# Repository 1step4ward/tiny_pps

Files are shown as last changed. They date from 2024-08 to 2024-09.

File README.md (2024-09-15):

# Tiny Programmable Power Supply

今は、USB機器向けのACアダプタやモバイルバッテリーは、一人一つ以上持っていると思います。最近では、そういった機器は、USB PD-PPSに対応していることが多く、USB PD-PPSとは、Power Delivery - Programmable Power Supplyと言う通り、電圧電流がプログラム可能な電源機能を持っていることを表しています。  

このリポジトリは、そのUSB PD PPSの機能を使った小型の可変電圧電源を作ることを目的としています。  

そして、同じような目的に使える素晴らしい製品がすでにありますので、興味のある人は、以下のリンクを参照ください。  
https://hackaday.io/project/192576-picopd-usb-c-pd-30-pps-trigger-with-rp2040

上記のものが日本では入手し難かったのと、単純に作りたかったため始めたプロジェクトです。

## Prototype 1.0

### ・外観
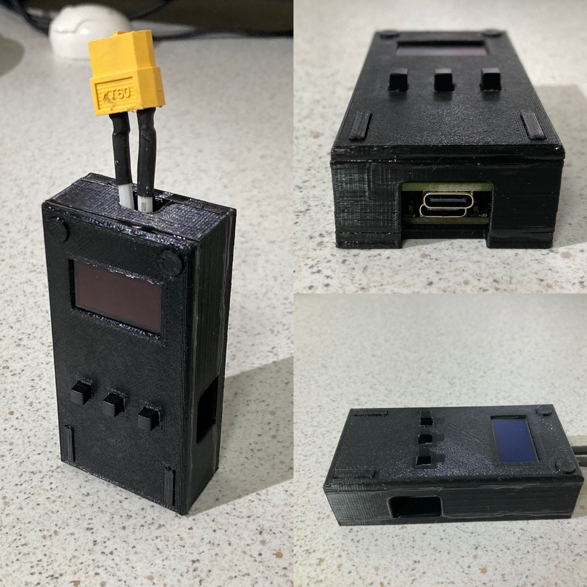
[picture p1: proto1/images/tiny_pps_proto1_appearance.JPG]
外観


### ・主要部品
- [AP33772使用 USB PD PPSコントローラー基板](https://aselectroworks.booth.pm/items/5621735)  
- Raspberry Pi Pico（代替品を使用）  
- [0.96インチ 128×64ドット有機ELディスプレイ(OLED) 白色](https://akizukidenshi.com/catalog/g/g112031/)  
- [タクトスイッチ](https://akizukidenshi.com/catalog/g/g112224)、[キートップ](https://akizukidenshi.com/catalog/g/g112429/)  
- パワーMOSFET IRFZ44N  
- コンデンサ  

出力のON/OFF回路部にパワーMOSFET、コンデンサを使用していますが、知識が乏しく適切な使用じゃないかもしれません。

### ・仕様
| 項目 | 数値 |
|-----|-----|
| 電圧範囲 | 3.3 - 21.0V 20mV刻み |
| 電流範囲 | 最大5A 50mA刻み |
|  | ※USB PD 3.0仕様の範囲、実際の使用時は電源ソースの能力による |
| 大きさ | 80 x 40 x 21mm |
| 重さ | 52g |
| 入出力 | 3ボタン、128x64 OLED、USB-C(電源ソース、プログラム)、XT60コネクタ(電力出力) |

### ・リンク
[ファームウェア](proto1/software/firmware/)  
[配線図](proto1/hardware/circuit/tiny_pps_proto1_bb.png)  
[ケースの3Dプリントモデル](proto1/hardware/3d-printed-case/)

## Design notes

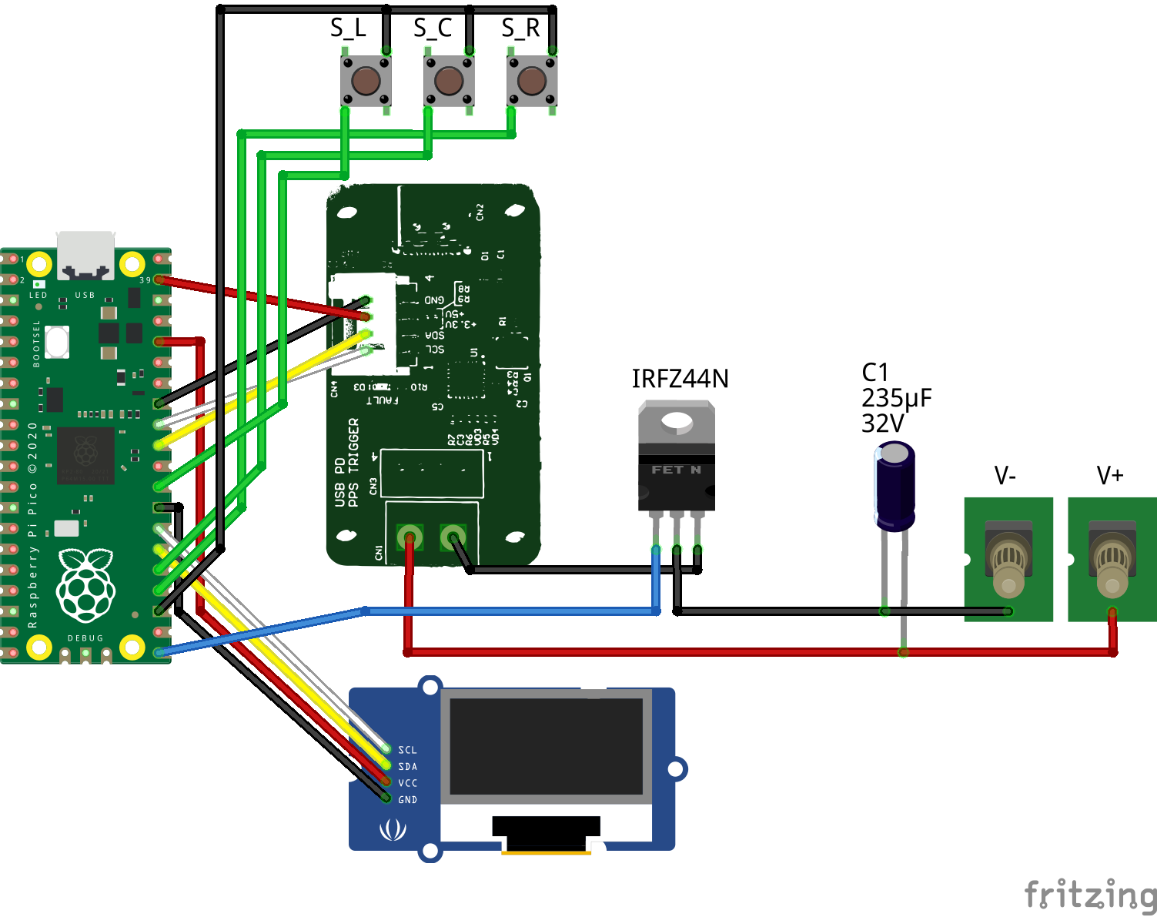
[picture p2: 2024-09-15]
proto1/hardware/circuit/tiny_pps_proto1_bb.png

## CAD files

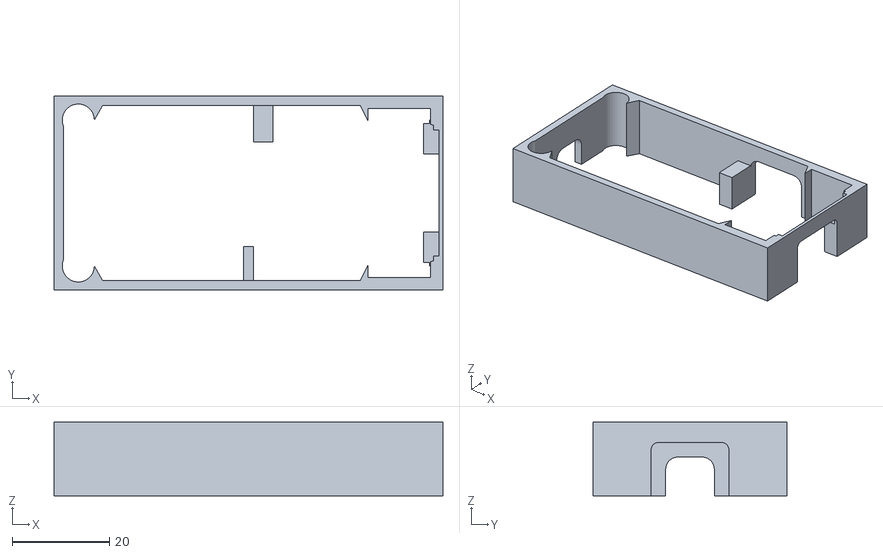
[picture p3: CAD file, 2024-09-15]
proto1/hardware/3d-printed-case/tinypps_proto1_wall.stl
80.0 x 40.0 x 15.2

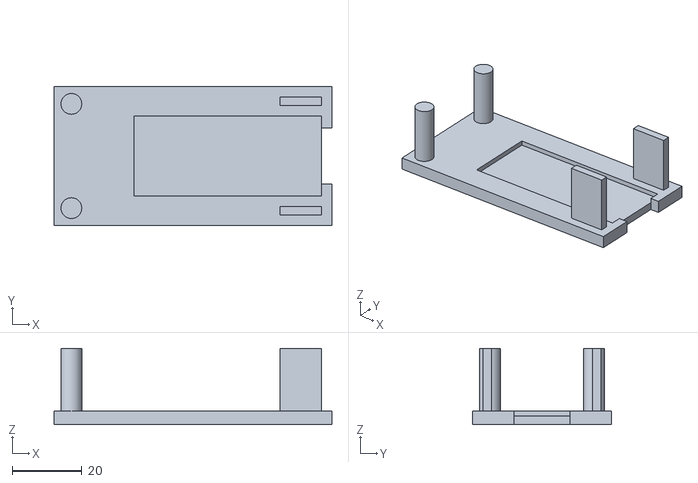
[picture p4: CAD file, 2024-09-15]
proto1/hardware/3d-printed-case/tinypps_proto1_bottom.stl
80.0 x 40.0 x 22.0

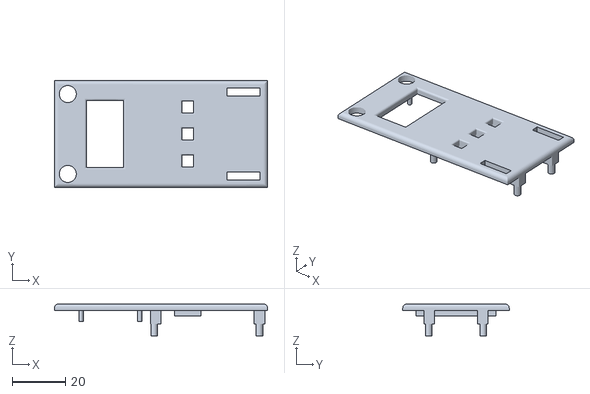
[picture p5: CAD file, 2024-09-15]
proto1/hardware/3d-printed-case/tinypps_proto1_top.stl
80.0 x 40.0 x 12.0

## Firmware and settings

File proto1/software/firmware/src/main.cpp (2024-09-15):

/*
  Example code that will cycle through all possble PPS voltage starting at 4.2V
  Will print out current reading through the 10mOhm sense resistor and blink LED
*/

#include <Arduino.h>
#include <AP33772_PS.h>
#include <Adafruit_GFX.h>
#include <Adafruit_SSD1306.h>

#define SCREEN_WIDTH 128 // OLED display width, in pixels
#define SCREEN_HEIGHT 64 // OLED display height, in pixels

// Declaration for an SSD1306 display connected to I2C (SDA, SCL pins)
// The pins for I2C are defined by the Wire-library. 
// On an arduino UNO:       A4(SDA), A5(SCL)
// On an arduino MEGA 2560: 20(SDA), 21(SCL)
// On an arduino LEONARDO:   2(SDA),  3(SCL), ...
#define OLED_RESET     -1 // Reset pin # (or -1 if sharing Arduino reset pin)
#define SCREEN_ADDRESS 0x3C ///< See datasheet for Address; 0x3D for 128x64, 0x3C for 128x32
Adafruit_SSD1306 display(SCREEN_WIDTH, SCREEN_HEIGHT, &Wire, OLED_RESET);
AP33772_PS usbpd(Wire1); // Automatically wire to Wire0,


bool state = 0;
int voltage = 3300;
int current = 3000;
int maxVoltage = 10000;
int minVoltage = 3300;
int maxCurrent = 3000;

int button_count0 = 0;
int button_count1 = 0;
int button_count2 = 0;
int button_count3 = 0;

int mode = 0;

/**
 * @brief Debug code to quickly check power supply profile PDOs
 * dump all PDOs profile into Serial port
 */
void printPDO_PPS()
{
    byte numPDO = usbpd.getLowCtrl()->getNumPDO();
    PDO_DATA_T* pdoData = usbpd.getLowCtrl()->getPdoData();
    for (byte i = 0; i < numPDO; i++)
    {
        if ((pdoData[i].byte3 & 0xF0) == 0xC0) // PPS PDO
        {
            display.print(i + 1); // PDO position start from 1
            display.print(":");
            display.print((float)(pdoData[i].pps.minVoltage) * 100 / 1000);
            display.print("V~");
            display.print((float)(pdoData[i].pps.maxVoltage) * 100 / 1000);
            display.print("V@");
            display.print((float)(pdoData[i].pps.maxCurrent) * 50 / 1000);
            display.println("A");
            
            minVoltage = pdoData[i].pps.minVoltage * 100;
            maxVoltage = pdoData[i].pps.maxVoltage * 100;
            maxCurrent = pdoData[i].pps.maxCurrent * 50;
        }
    }
}

void setup()
{
  Wire.setSDA(20);
  Wire.setSCL(21);
  Wire.begin();

  usbpd.setup(26, 27);

  pinMode(25, OUTPUT); //Built in LED
  pinMode(23, OUTPUT); //Load Switch
  pinMode(16, INPUT_PULLDOWN); //MOSFET

  pinMode(18, INPUT_PULLUP);
  pinMode(19, INPUT_PULLUP);
  pinMode(22, INPUT_PULLUP);

  Serial.begin(115200);

  // SSD1306_SWITCHCAPVCC = generate display voltage from 3.3V internally
  if(!display.begin(SSD1306_SWITCHCAPVCC, SCREEN_ADDRESS)) {
    Serial.println(F("SSD1306 allocation failed"));
    for(;;); // Don't proceed, loop forever
  }
  // Clear the buffer
  display.clearDisplay();
  display.setTextSize(1);             // Normal 1:1 pixel scale
  display.setTextColor(SSD1306_WHITE);        // Draw white text
  display.setCursor(0,0);             // Start at top-left corner
  display.println("initializing...");
  display.display();

  usbpd.begin(); // Start pulling the PDOs from power supply

  digitalWrite(23, HIGH);

  // Clear the buffer
  display.clearDisplay();
  display.display();
}

void loop()
{
  char button[5] = "    ";

  display.clearDisplay();

  display.setTextSize(1);             // Normal 1:1 pixel scale
  display.setTextColor(SSD1306_WHITE);        // Draw white text
  display.setCursor(0,0);             // Start at top-left corner

  PinStatus lbutton, rbutton, mbutton;
  lbutton = digitalRead(22);
  rbutton = digitalRead(18);
  mbutton = digitalRead(19);

  if (mode == 0) {
    // voltage edit mode

    if (rbutton == LOW) {
      button[2] = 'x';
      button_count0 += 1;
      if (button_count0 > 5 && voltage < maxVoltage) {
        voltage += 100;
      }
    } else {
      button[2] = 'o';
      button_count0 = 0;
    }
    if (lbutton == LOW) {
      button[0] = 'x';
      button_count1 += 1;
      if (button_count1 > 5 && voltage > minVoltage) {
        voltage -= 100;
      }
    } else {
      button[0] = 'o';
      button_count1 = 0;
    }
  } else {
    // current edit mode

    if (rbutton == LOW) {
      button[2] = 'x';
      button_count0 += 1;
      if (button_count0 > 5 && current < maxCurrent) {
        current += 20;
      }
    } else {
      button[2] = 'o';
      button_count0 = 0;
    }
    if (lbutton == LOW) {
      button[0] = 'x';
      button_count1 += 1;
      if (button_count1 > 5 && current > 0) {
        current -= 20;
      }
    } else {
      button[0] = 'o';
      button_count1 = 0;
    }
  }

  if ((lbutton == LOW) && (rbutton == LOW)) {
    button_count3 += 1;
    if (button_count3 > 5) {
      if (mode == 0) {
        mode = 1;
      } else {
        mode = 0;
      }
      button_count3 = 0;
    }
  } else {
    button_count3 = 0;
  }

  bool enable = false;
  if (mbutton == LOW) {
    button[1] = 'x';
    button_count2 += 1;
    if (button_count2 > 5) {
      usbpd.getOutput(enable);
      if (enable) {
        usbpd.setOutput(false);
      } else {
        usbpd.setOutput(true);
      }
      button_count2 = 0;
    }
  } else {
    button[1] = 'o';
    button_count2 = 0;
  }

  usbpd.setOperatingCurrent(current);
  usbpd.setVoltage(voltage);
  
  display.print(button);
  if (mode == 0) {
    display.print("[V]");
  } else {
    display.print("[C]");
  }
  usbpd.getOutput(enable);
  if (enable) {
    display.println("[ON]");
  } else {
    display.println("[OFF]");
  }
  printPDO_PPS();
  display.print("W (V): ");
  display.println((float)voltage / 1000);
  display.print("W (A): ");
  display.println((float)current / 1000);

  display.print("R (V): ");
  display.println((float)usbpd.getLowCtrl()->readVoltage() / 1000);
  display.print("R (A): ");
  int rcurrent;
  usbpd.getCurrent(rcurrent);
  display.println((float)rcurrent / 1000);

  display.display();
  delay(100);
}

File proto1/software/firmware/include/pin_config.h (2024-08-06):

/**
 * @file pin_config.h
 * @brief Pin Configuration Header File
 * @details Raspberry Pi Pico Pin Configuration
 */

#ifndef __PIN_CONFIG__
#define __PIN_CONFIG__

/**
 * I2C Pin Configuration
 */
#define SSD1306_SDA_PIN 20
#define SSD1306_SCL_PIN 21

#define AP33772_SDA_PIN 26
#define AP33772_SCL_PIN 27

/**
 * Button Pin Configuration
 */
#define LEFT_BUTTON_PIN 18
#define RIGHT_BUTTON_PIN 19
#define ENTER_BUTTON_PIN 22

/**
 * LED Pin Configuration
 */
#define PWR_LED_PIN 23


#endif
